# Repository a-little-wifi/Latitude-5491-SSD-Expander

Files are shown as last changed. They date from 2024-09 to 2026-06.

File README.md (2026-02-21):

# Latitude 5491 SSD Expander
This project is a PCB meant to fit in the large empty space around the Dell Latitude 5491's M.2 SSD slot. Together with a firmware modification, it should allow me to fit 2 2280 NVMe SSDs with 2 PCIe lanes each.

This is also an experiment to figure out PCIe bifurcation in general. In this case I'm using a Renesas 9ZXL0651AKLF clock buffer with 6 outputs, but I'm only using the first 2 for this board.

Should in theory also work on the H-class CPU version of the Latitude 5480, but not the U-class 5480 and 5490, those only have 2 PCIe lanes for the SSD slot in the first place.

~~Impedance is tuned for Aisler's 4-layer 0.8mm process~~ (thanks [Aisler](https://aisler.net/) for sponsoring the fabrication of this board!)  
Turns out the impedance and possibly other factors are not quite right, the current design has issues maintaining the PCIe link on the first slot, be aware if you plan to use this design.

### pics:

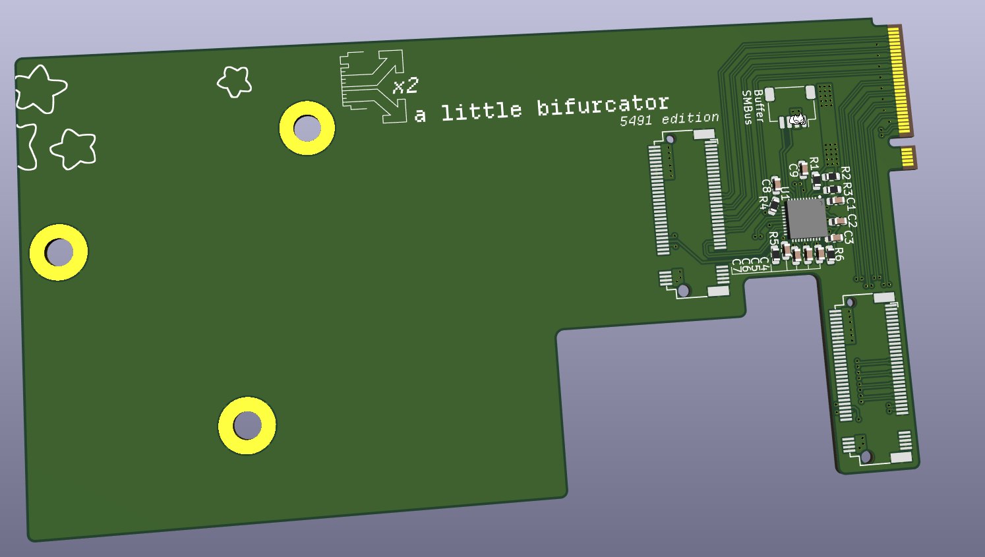
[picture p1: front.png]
> 
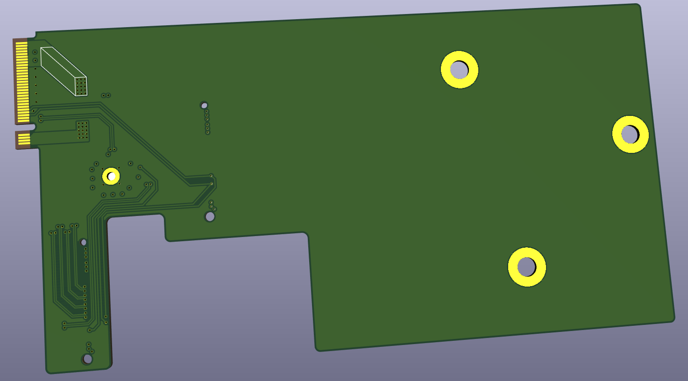
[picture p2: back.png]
> 

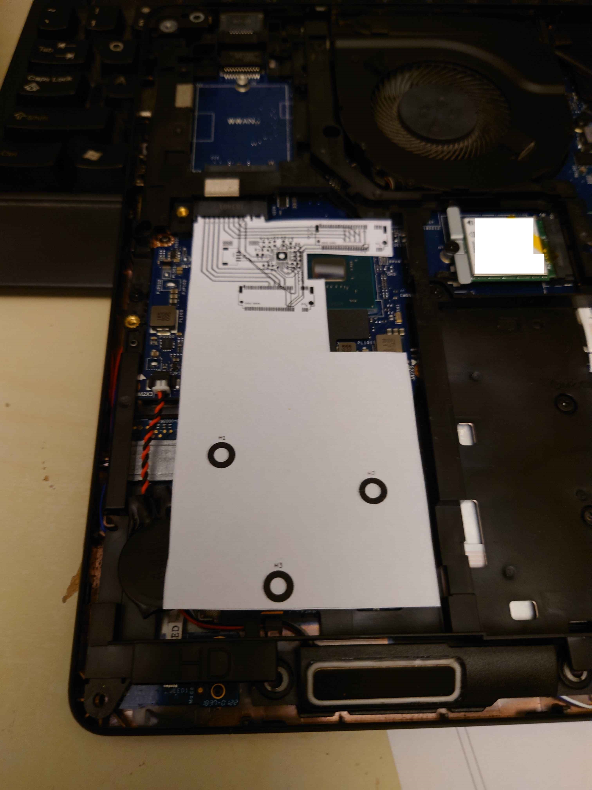
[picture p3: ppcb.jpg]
> 
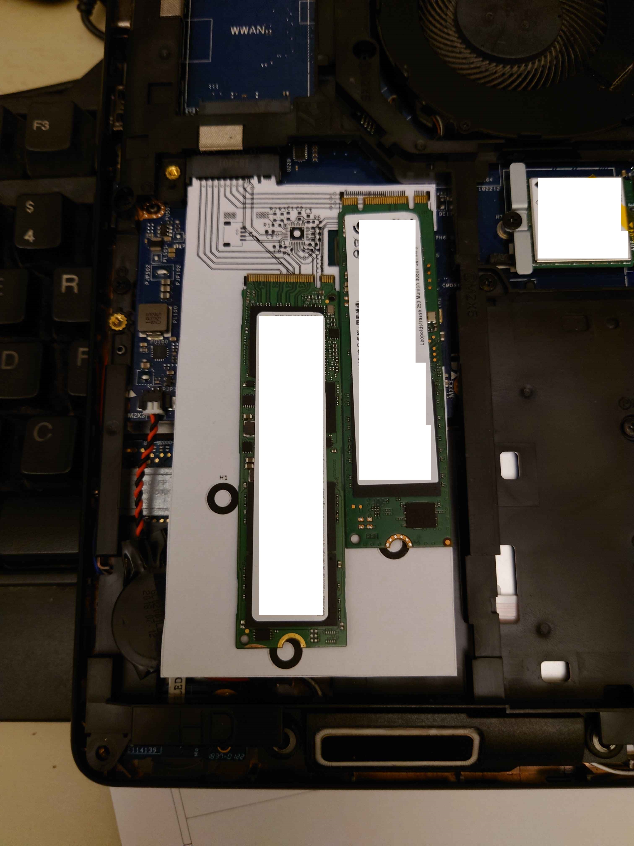
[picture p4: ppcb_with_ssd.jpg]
> 

# Results:

## It works!
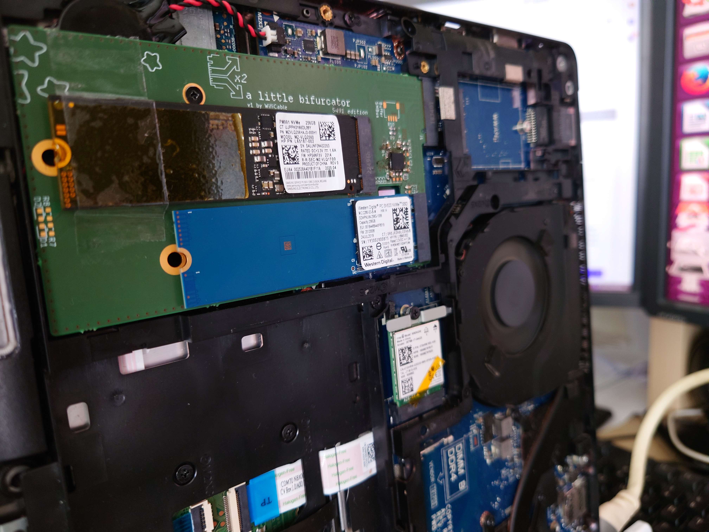
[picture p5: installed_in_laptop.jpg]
> 

> Bifurcation board with 2 SSDs installed in a Latitude 5491

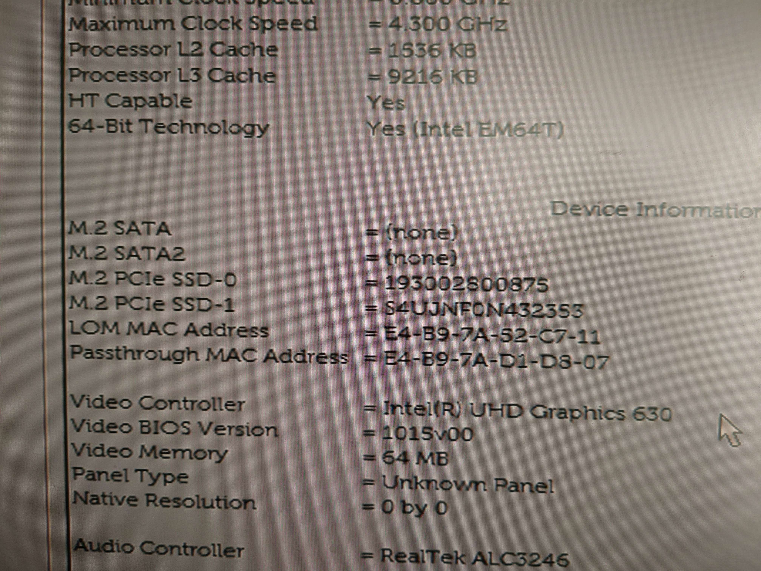
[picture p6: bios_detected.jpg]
> 

> Both SSDs showing up in the setup menu (the second one is showing in the entry usually meant for the WWAN slot lol)

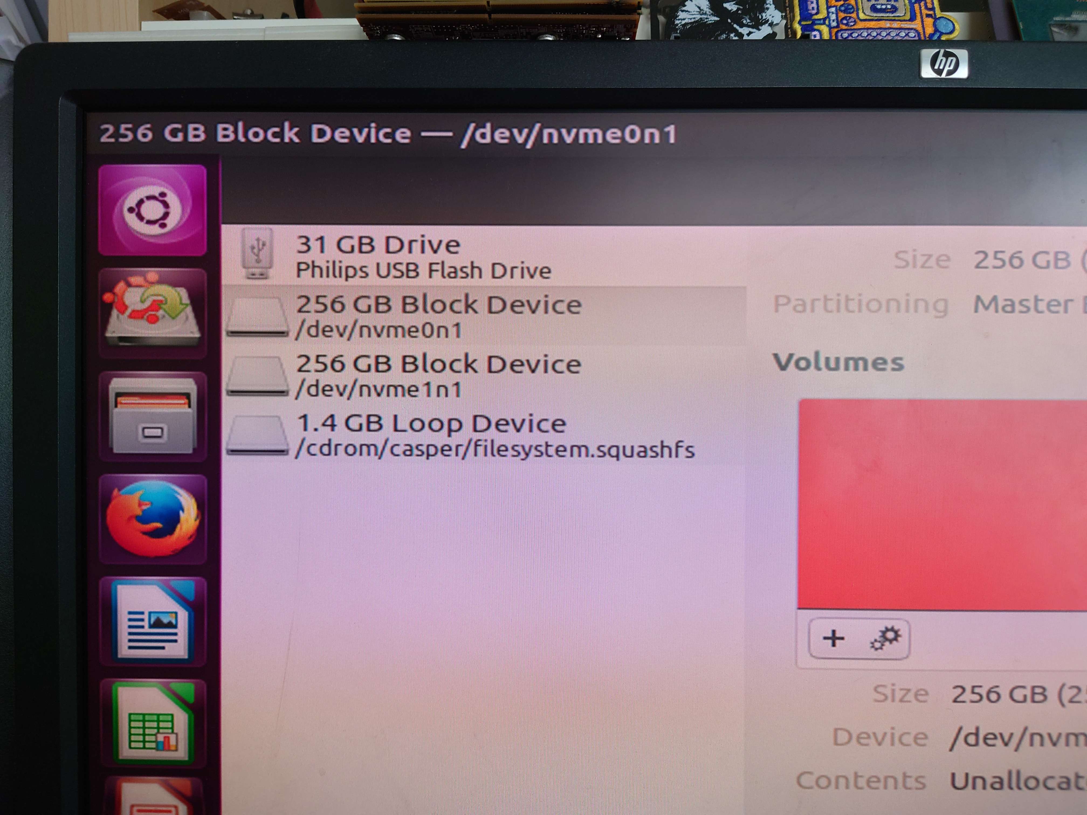
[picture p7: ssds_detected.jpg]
> 

> Both SSDs detected in Gnome Disks (Ubuntu 16.04 live)

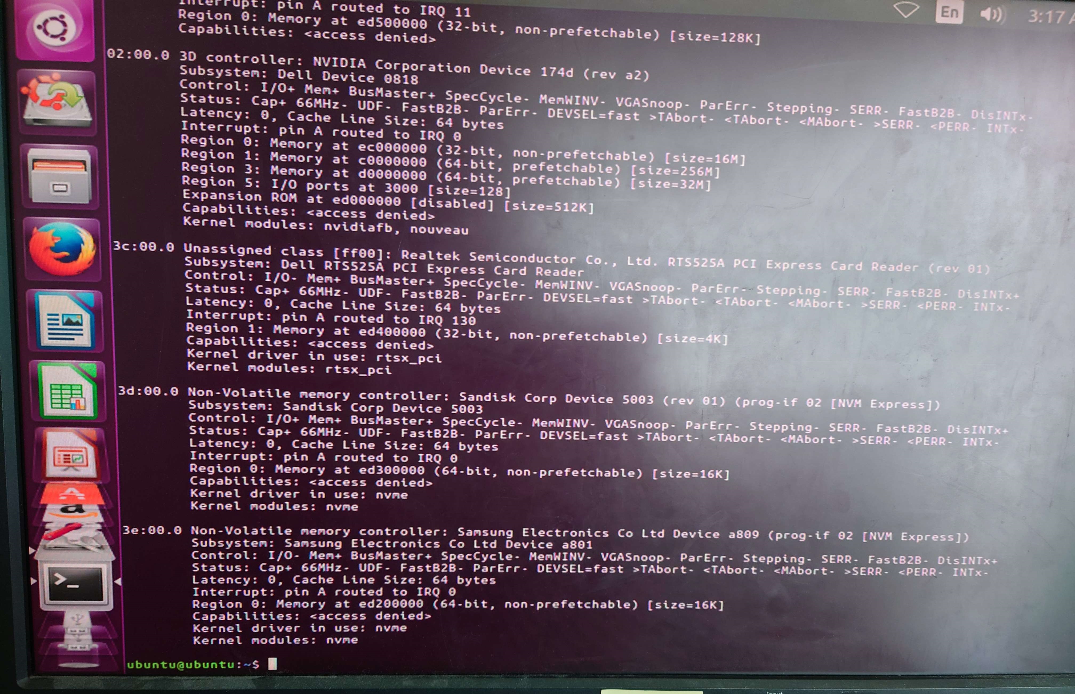
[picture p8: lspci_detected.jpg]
> 

> Both SSDs showing up in lspci (not shown: both running at PCIe x2 as expected)

## How to make it work:

To get this working, you need to modify the Flex I/O configuration of your laptop by dumping the content of the BIOS chip, loading it into Intel's Flash Image Tool (mfit) (version 12.0.85.1919 for the Latitude 5491), navigating to the Flex I/O section and changing the PCIe Port Configuration for PCIe Controller 3 (Port 9-12) (this is the one connected to the M-key slot on the 5491) from 1x4 to 2x2:

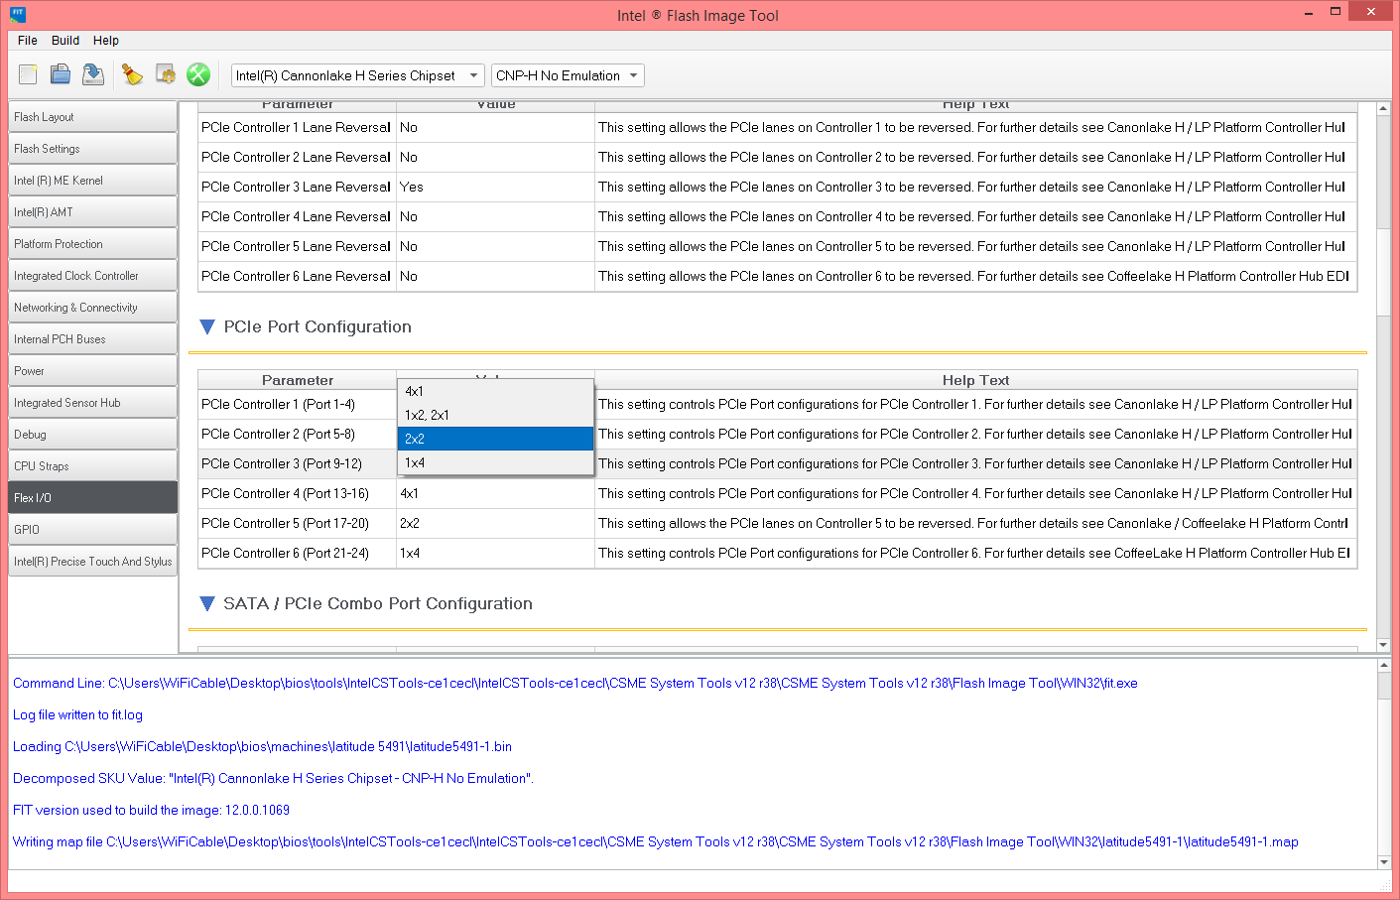
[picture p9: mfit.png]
> 

> Changing the PCIe port from 1x4 to 2x2 in mfit

Then click the Build Image button at the top of the mfit window to generate a new bios binary file that can be flashed back onto the laptop (outimage.bin in the same directory as fit.exe)

For your first boot you might need to clear the cmos to get it to run and also give it a few reboot cycles. 

## I provide no warranty on any of this, I am not responsible if you mess up your machine  
This is only an experiment to prove it's possible for end users to bifurcate and generally change the configuration of the PCH PCIe lanes in their Intel-based laptop

For the next bifurcation adapter I'll probably use the Renesas 9DBL411BGLFT clock buffer instead, looks easier to solder and is readily available

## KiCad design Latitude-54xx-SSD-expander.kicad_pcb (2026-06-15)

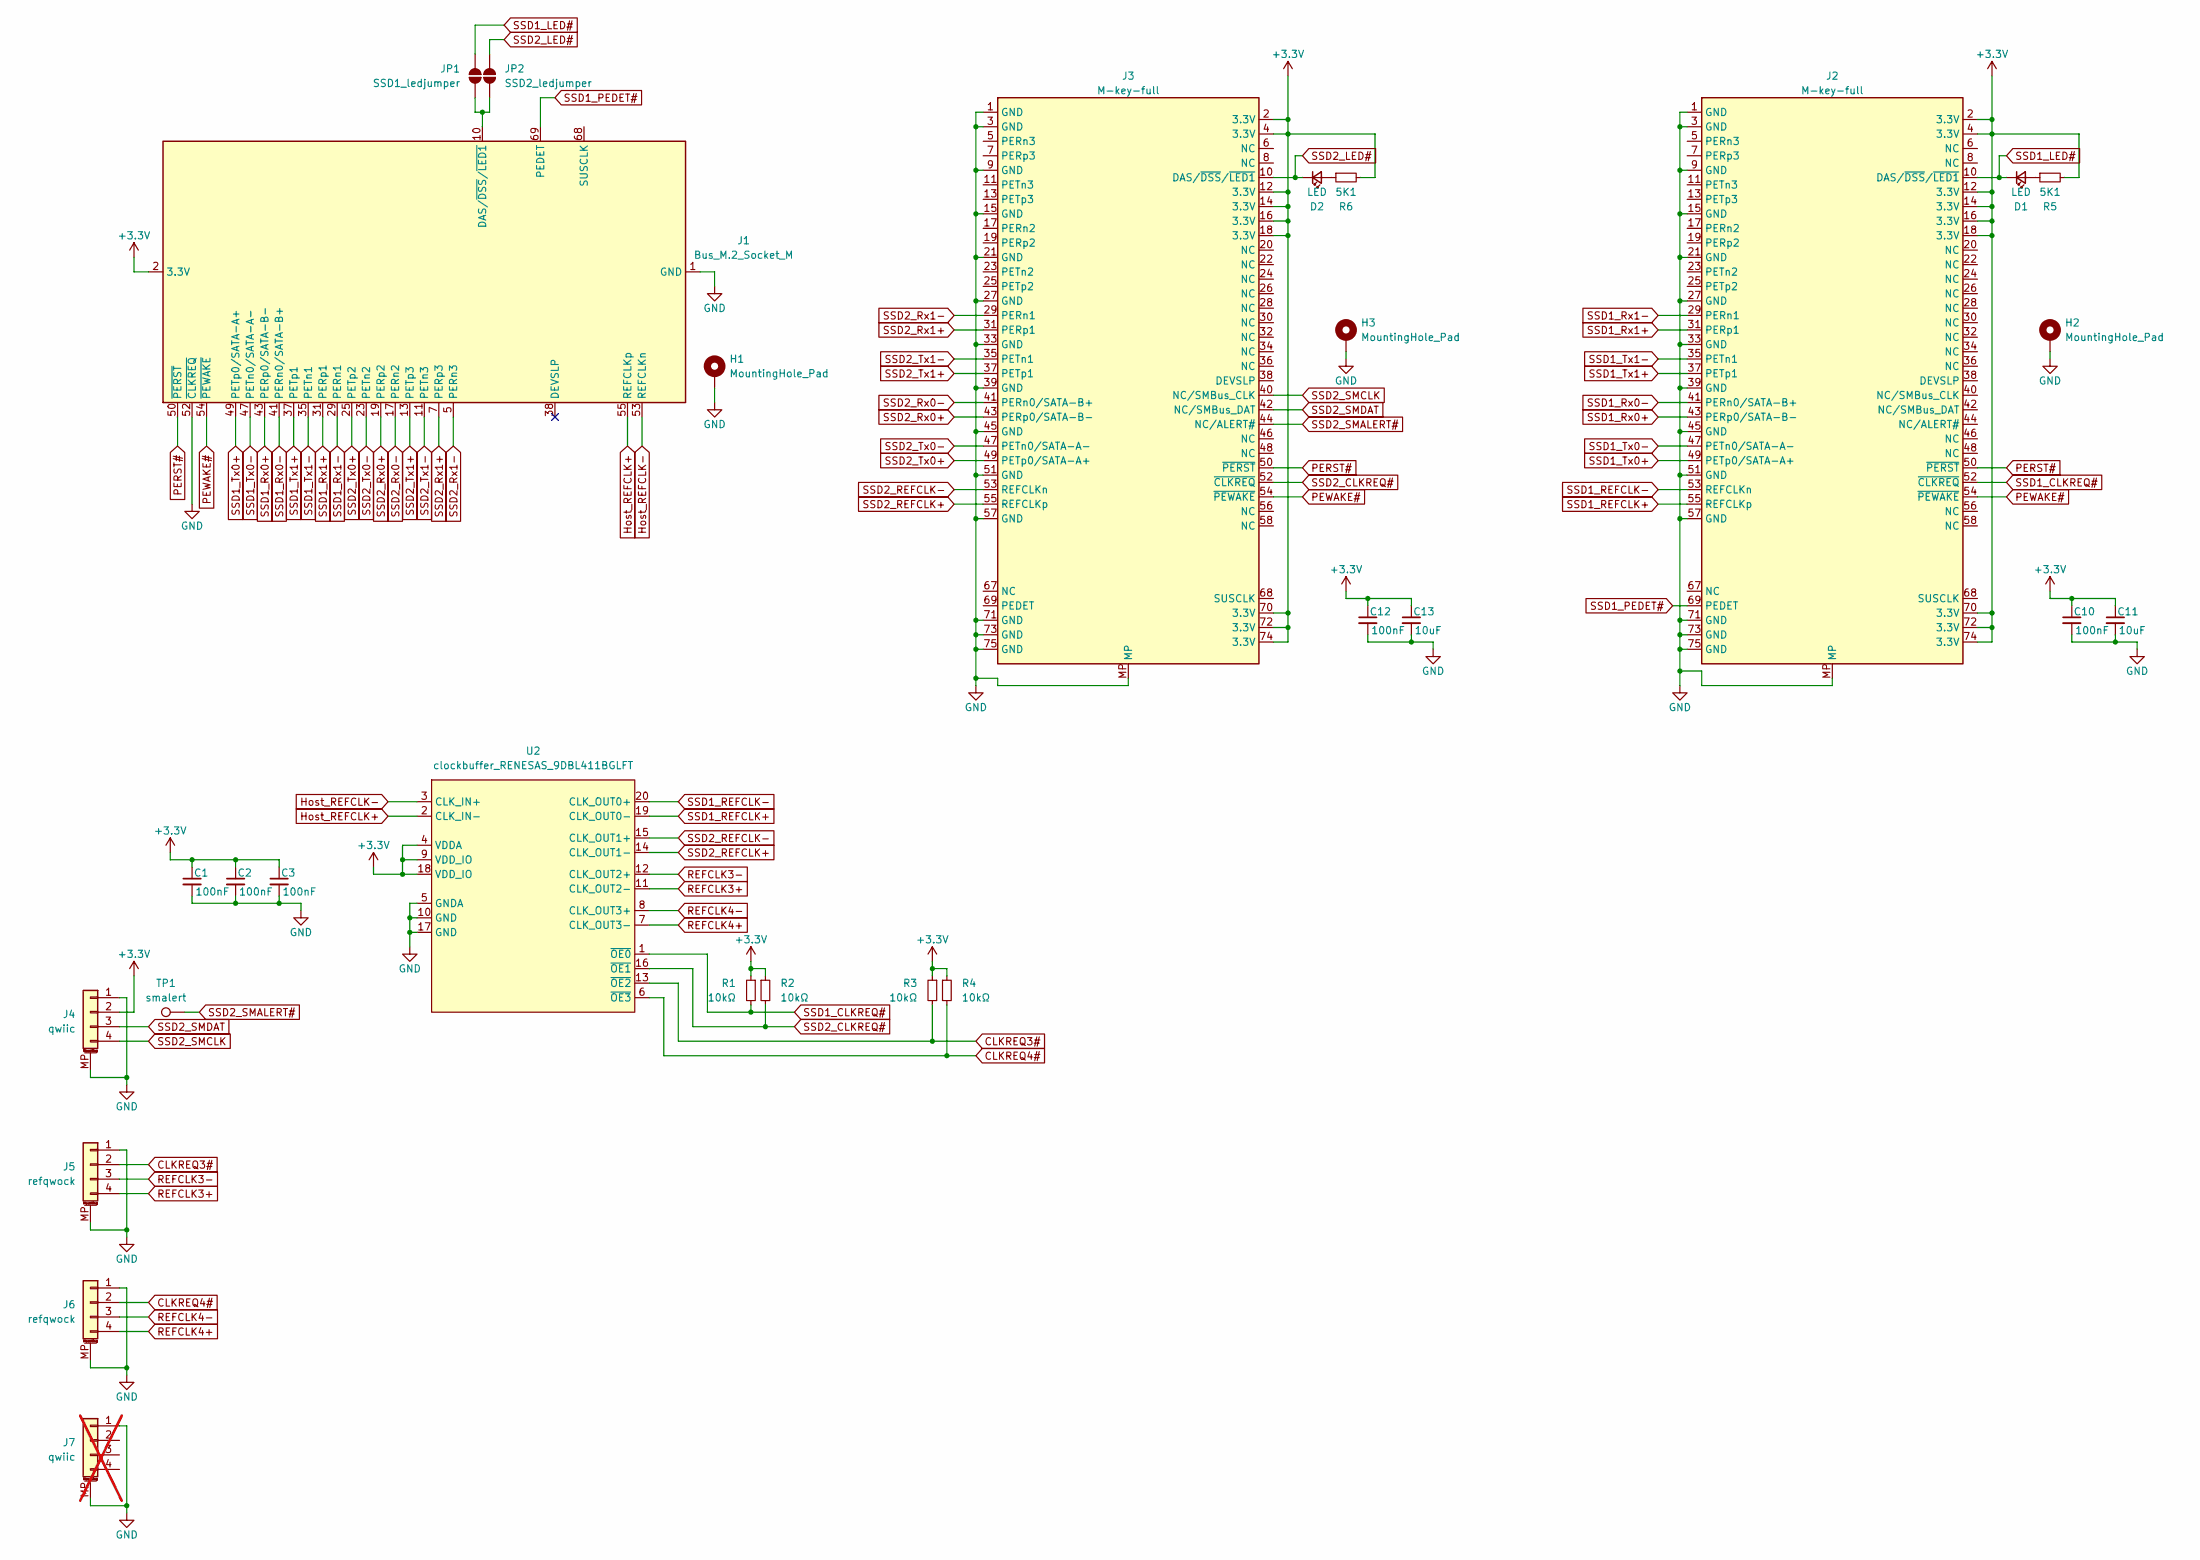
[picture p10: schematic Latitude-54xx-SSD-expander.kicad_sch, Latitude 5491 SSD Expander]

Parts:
C1, C2, C3, C10, C12: 100nF; C_0603_1608Metric
C11, C13: 10uF; C_0603_1608Metric
D1, D2: LED; D_0603_1608Metric
H1: MountingHole_Pad; MountingHole_3.5mm_Pad
H2, H3: MountingHole_Pad; MountingHole_4mm_Pad
J1: Bus_M.2_Socket_M; NGFF_M
J2, J3: M-key-full; m-key
J4: qwiic; JST_SH_SM04B-SRSS-TB_1x04-1MP_P1.00mm_Horizontal
J5, J6: refqwock; JST_SH_SM04B-SRSS-TB_1x04-1MP_P1.00mm_Horizontal
J7: qwiic; JST_SH_SM04B-SRSS-TB_1x04-1MP_P1.00mm_Horizontal; not fitted
JP1: SSD1_ledjumper; mySolderJumper-1x0.5mm
JP2: SSD2_ledjumper; mySolderJumper-1x0.5mm
R1, R2, R3, R4: 10kΩ; R_0603_1608Metric
R5, R6: 5K1; R_0603_1608Metric
TP1: smalert; TestPoint_Pad_D1.0mm
U2: clockbuffer_RENESAS_9DBL411BGLFT; clockbuffer_RENESAS 9DBL411BGLFT; LCSC Part C2649348

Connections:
+3.3V: C1.1, C2.1, C3.1, C10.1, C11.1, C12.1, C13.1, J1.2 (3.3V), J1.4 (3.3V), J1.12 (3.3V), J1.14 (3.3V), J1.16 (3.3V), J1.18 (3.3V), J1.70 (3.3V), J1.72 (3.3V), J1.74 (3.3V), J2.2 (3.3V), J2.4 (3.3V), J2.12 (3.3V), J2.14 (3.3V), J2.16 (3.3V), J2.18 (3.3V), J2.70 (3.3V), J2.72 (3.3V), J2.74 (3.3V), J3.2 (3.3V), J3.4 (3.3V), J3.12 (3.3V), J3.14 (3.3V), J3.16 (3.3V), J3.18 (3.3V), J3.70 (3.3V), J3.72 (3.3V), J3.74 (3.3V), J4.2, R1.1, R2.1, R3.1, R4.1, R5.2, R6.2, U2.4 (VDDA), U2.9 (VDD_IO), U2.18 (VDD_IO)
CLKREQ3#: J5.2, R3.2, U2.13 (~OE2)
CLKREQ4#: J6.2, R4.2, U2.6 (~OE3)
GND: C1.2, C2.2, C3.2, C10.2, C11.2, C12.2, C13.2, H1.1, H2.1, H3.1, J1.1 (GND), J1.3 (GND), J1.9 (GND), J1.15 (GND), J1.21 (GND), J1.27 (GND), J1.33 (GND), J1.39 (GND), J1.45 (GND), J1.51 (GND), J1.52 (~CLKREQ), J1.57 (GND), J1.71 (GND), J1.73 (GND), J1.75 (GND), J2.1 (GND), J2.3 (GND), J2.9 (GND), J2.15 (GND), J2.21 (GND), J2.27 (GND), J2.33 (GND), J2.39 (GND), J2.45 (GND), J2.51 (GND), J2.57 (GND), J2.71 (GND), J2.73 (GND), J2.75 (GND), J2.MP, J3.1 (GND), J3.3 (GND), J3.9 (GND), J3.15 (GND), J3.21 (GND), J3.27 (GND), J3.33 (GND), J3.39 (GND), J3.45 (GND), J3.51 (GND), J3.57 (GND), J3.71 (GND), J3.73 (GND), J3.75 (GND), J3.MP, J4.1, J4.MP (MountPin), J5.1, J5.MP (MountPin), J6.1, J6.MP (MountPin), J7.1, J7.MP (MountPin), U2.5 (GNDA), U2.10 (GND), U2.17 (GND)
Host_REFCLK+: J1.55 (REFCLKp), U2.2 (CLK_IN-)
Host_REFCLK-: J1.53 (REFCLKn), U2.3 (CLK_IN+)
unnamed: D1.2 (A), R5.1
unnamed: D2.2 (A), R6.1
unnamed: J1.10 (DAS/~DSS/~LED1), JP1.1 (A), JP2.1 (A)
PERST#: J1.50 (~PERST), J2.50 (~PERST), J3.50 (~PERST)
PEWAKE#: J1.54 (~PEWAKE), J2.54 (~PEWAKE), J3.54 (~PEWAKE)
REFCLK3+: J5.4, U2.11 (CLK_OUT2-)
REFCLK3-: J5.3, U2.12 (CLK_OUT2+)
REFCLK4+: J6.4, U2.7 (CLK_OUT3-)
REFCLK4-: J6.3, U2.8 (CLK_OUT3+)
SSD1_CLKREQ#: J2.52 (~CLKREQ), R1.2, U2.1 (~OE0)
SSD1_LED#: D1.1 (K), J2.10 (DAS/~DSS/~LED1), JP1.2 (B)
SSD1_PEDET#: J1.69 (PEDET), J2.69 (PEDET)
SSD1_REFCLK+: J2.55 (REFCLKp), U2.19 (CLK_OUT0-)
SSD1_REFCLK-: J2.53 (REFCLKn), U2.20 (CLK_OUT0+)
SSD1_Rx0+: J1.43 (PERp0/SATA-B-), J2.43 (PERp0/SATA-B-)
SSD1_Rx0-: J1.41 (PERn0/SATA-B+), J2.41 (PERn0/SATA-B+)
SSD1_Rx1+: J1.31 (PERp1), J2.31 (PERp1)
SSD1_Rx1-: J1.29 (PERn1), J2.29 (PERn1)
SSD1_Tx0+: J1.49 (PETp0/SATA-A+), J2.49 (PETp0/SATA-A+)
SSD1_Tx0-: J1.47 (PETn0/SATA-A-), J2.47 (PETn0/SATA-A-)
SSD1_Tx1+: J1.37 (PETp1), J2.37 (PETp1)
SSD1_Tx1-: J1.35 (PETn1), J2.35 (PETn1)
SSD2_CLKREQ#: J3.52 (~CLKREQ), R2.2, U2.16 (~OE1)
SSD2_LED#: D2.1 (K), J3.10 (DAS/~DSS/~LED1), JP2.2 (B)
SSD2_REFCLK+: J3.55 (REFCLKp), U2.14 (CLK_OUT1-)
SSD2_REFCLK-: J3.53 (REFCLKn), U2.15 (CLK_OUT1+)
SSD2_Rx0+: J1.19 (PERp2), J3.43 (PERp0/SATA-B-)
SSD2_Rx0-: J1.17 (PERn2), J3.41 (PERn0/SATA-B+)
SSD2_Rx1+: J1.7 (PERp3), J3.31 (PERp1)
SSD2_Rx1-: J1.5 (PERn3), J3.29 (PERn1)
SSD2_SMALERT#: J3.44 (NC/ALERT#), TP1.1
SSD2_SMCLK: J3.40 (NC/SMBus_CLK), J4.4
SSD2_SMDAT: J3.42 (NC/SMBus_DAT), J4.3
SSD2_Tx0+: J1.25 (PETp2), J3.49 (PETp0/SATA-A+)
SSD2_Tx0-: J1.23 (PETn2), J3.47 (PETn0/SATA-A-)
SSD2_Tx1+: J1.13 (PETp3), J3.37 (PETp1)
SSD2_Tx1-: J1.11 (PETn3), J3.35 (PETn1)

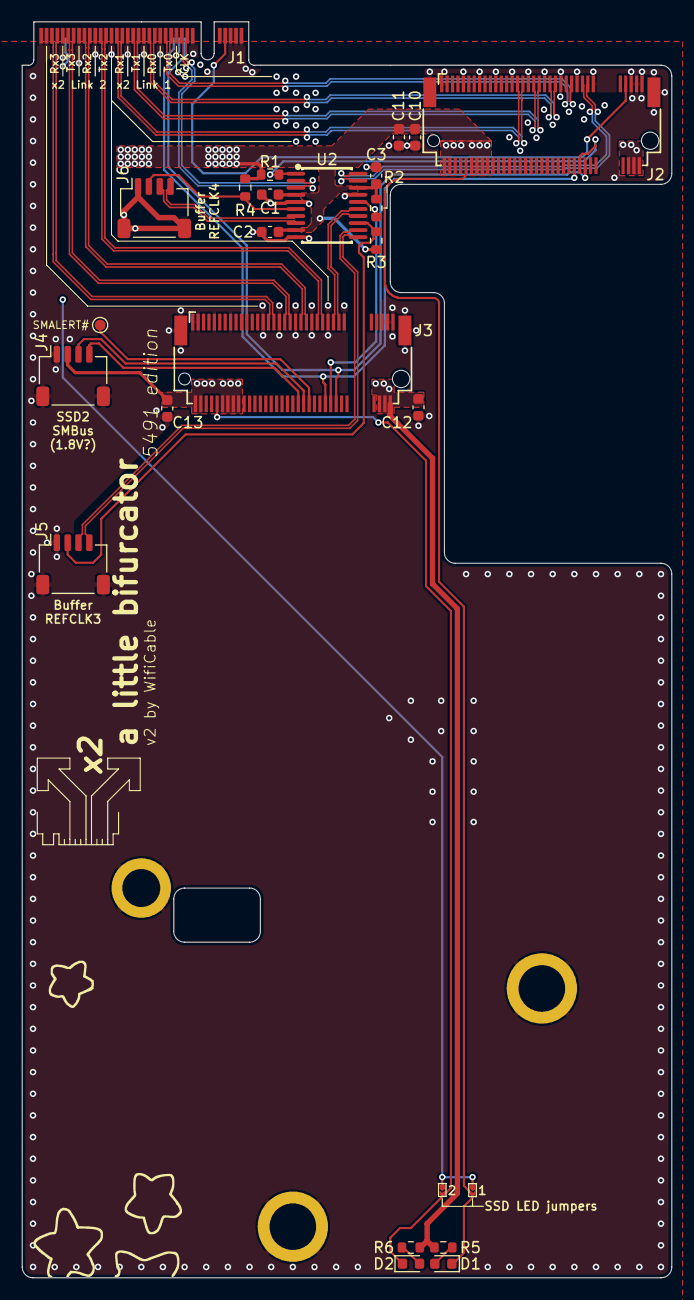
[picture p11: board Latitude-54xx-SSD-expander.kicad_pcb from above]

Board: 4 copper layers, 60.0 x 116.0 mm, 28 parts (0 on the bottom side), 43 nets.

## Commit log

2024-09-13 Adjusted line thickness for printing
    [Latitude-54xx-SSD-expander.kicad_pcb]
2024-09-14 Rearranged schematic for readability
    [Latitude-54xx-SSD-expander.kicad_sch]
2024-09-14 brick :3
    [Latitude-54xx-SSD-expander.kicad_pcb]
2024-09-14 logo concept on the silkscreen
    [Latitude-54xx-SSD-expander.kicad_pcb]
2024-09-14 Silkscreen adjustments
    [Latitude-54xx-SSD-expander.kicad_pcb]
2024-09-14 Added todo list
    [Latitude-54xx-SSD-expander.kicad_pcb]
2024-09-16 Added capacitors for m.2 slots and ground vias for pcie
    [Latitude-54xx-SSD-expander.kicad_pcb, Latitude-54xx-SSD-expander.kicad_sch]
2024-09-18 fixed m.2 slot refdes
    [Latitude-54xx-SSD-expander.kicad_pcb]
2024-09-21 Added activity leds
    [Latitude-54xx-SSD-expander.kicad_pcb, Latitude-54xx-SSD-expander.kicad_sch]
2024-09-28 led placement and traces
    this was supposed to already be there???
    [Latitude-54xx-SSD-expander.kicad_pcb]
2024-10-28 Added hole for Dell's silly mount
    [Latitude-54xx-SSD-expander.kicad_pcb]
2024-10-28 Lots of small fixes to prepare for production
    more ground vias,, fixed a diffpair reference layer issue
    [Latitude-54xx-SSD-expander.kicad_pcb]
2024-10-28 Added i2c pullups
    [Latitude-54xx-SSD-expander.kicad_pcb, Latitude-54xx-SSD-expander.kicad_sch]
2024-10-28 page note
    [Latitude-54xx-SSD-expander.kicad_sch]
2024-10-28 edge vias
    for some reason, they probably look cool
    [Latitude-54xx-SSD-expander.kicad_pcb]
2024-10-28 Added user defined bridges for aisler
    They're on layer user 3, move to edge.cuts to use them
    [Latitude-54xx-SSD-expander.kicad_pcb]
2025-05-26 Connected PEDET for first slot
    [Latitude-54xx-SSD-expander.kicad_pcb, Latitude-54xx-SSD-expander.kicad_sch]
2026-02-21 Added first slot link issues warning
2026-03-05 v2
    replaced buffer with 9DBL411BGLFT, fixed impedance (for JLC), added spare refclk breakouts, added ssd smbus breakout, added host activity LED option, improved PCIe pair layout. todo: fix standoff footprints
    [Latitude-54xx-SSD-expander.kicad_pcb, Latitude-54xx-SSD-expander.kicad_sch]
2026-03-05 Minor tweaks
    Added pinouts to silkscreen
    [Latitude-54xx-SSD-expander.kicad_pcb]
2026-03-06 fixed m.2 standoff footprints, v2 done?
    [Latitude-54xx-SSD-expander.kicad_pcb, Latitude-54xx-SSD-expander.kicad_sch]
2026-03-06 fixed m.2 standoff footprint for real this time
    [Latitude-54xx-SSD-expander.kicad_pcb]
2026-03-06 changed led jumpers to custom solderjumpers
    [Latitude-54xx-SSD-expander.kicad_pcb, Latitude-54xx-SSD-expander.kicad_sch]
2026-03-06 more small tweaks
    [Latitude-54xx-SSD-expander.kicad_pcb]
2026-03-06 More minor changes!
    final final version fr copy(3) last one finished definitely done now™️
    [Latitude-54xx-SSD-expander.kicad_pcb]
2026-06-15 moar ground vias
    [Latitude-54xx-SSD-expander.kicad_pcb]
